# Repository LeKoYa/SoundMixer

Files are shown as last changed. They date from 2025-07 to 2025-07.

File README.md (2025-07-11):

# SoundMixer
A deej-powered Soundmixer for individual volume control with rotary encoders, leds, buttons and oled support. I've also made an enclosure that is supposed to be mounted below a table.



This is still an early version and rebuilding your own might become very tricky. I am actively working on a second version that will be easier to build and assemble.

# Hardware
The soundmixer uses the following things:
- Arduino nano
- 5x Custom PCBs with 25 ws2812 LEDs and rotary encoder
- 1x 1.3" i2c oled screen (ssd1306)
- 2x mx-switch
- 2x pull-up resistors
- A lot of cables

### LED-PCB
For the LEDs i've designed a custom pcb with a size of 3x3cm. On the front side are 25 1010 ws2812 LEDs, neatly arranged around a rotary encoder (PEC11R-4015F-S0024). The backside features some capacitors and resistors used mainly for the encoder. It also features a small 7-pin molex picoblade connector due to the limited space.





The pcb was designed in kicad. I am still working on a version2 that features two pcbs stacked on top of each other, so the encoder does not stick out too far above the leds.

### Enclosure
The entire enclosure is 3d-printed, mainly in PLA. The diffusers in front of the led rings are made out of translucent PETG.
The parts are screwed together with some M2.5 screws. 



# Software

### PC Side
On the pc side, it uses a fork of the original deej project [found here](https://github.com/michaelwschultz/deej). 

### Arduino Side
For the arduino i wrote my own firmware (see the [software](Software) folder), with the help of platformio using some arduino libraries.

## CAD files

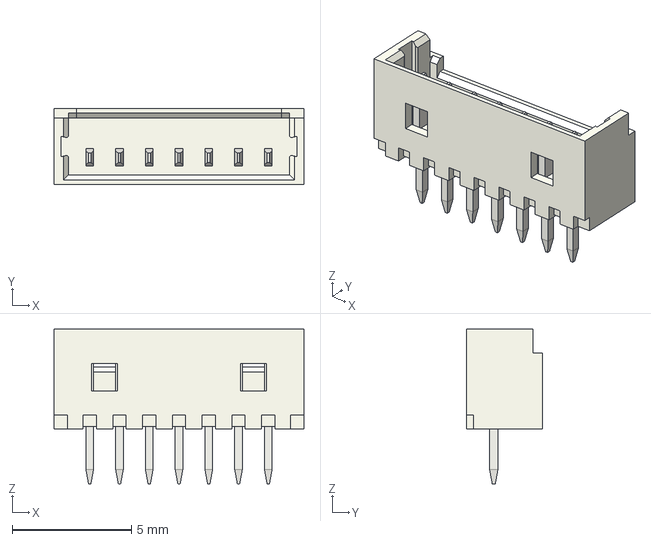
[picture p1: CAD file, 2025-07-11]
Hardware/led-pcb/3dmodels/Molex_PicoBlade_53047-0710.stp
10.5 x 3.20 x 6.50 mm

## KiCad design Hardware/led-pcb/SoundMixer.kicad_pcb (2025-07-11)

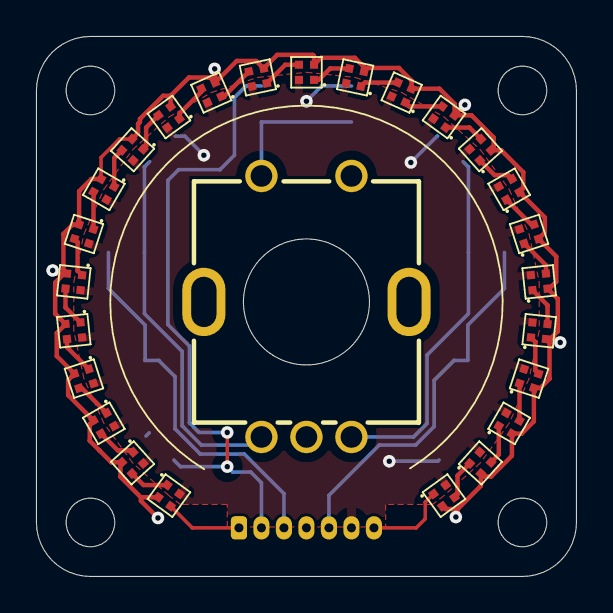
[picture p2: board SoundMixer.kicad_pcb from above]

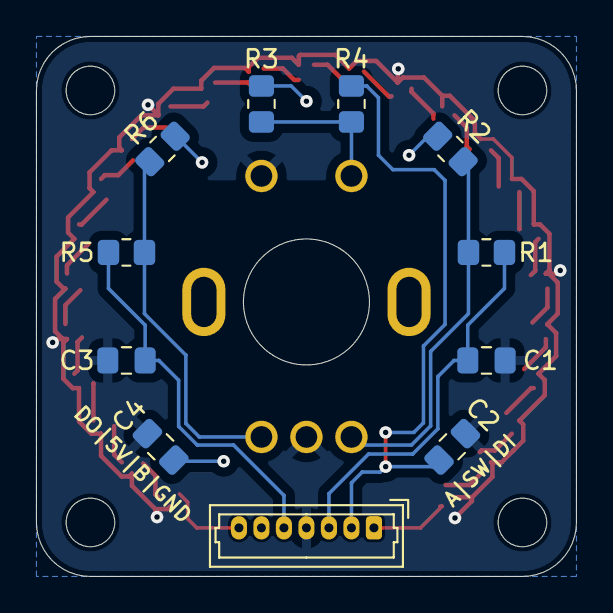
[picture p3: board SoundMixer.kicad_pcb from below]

Board: 2 copper layers, 30.0 x 30.0 mm, 41 parts (11 on the bottom side), 34 nets.

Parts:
C1, C2, C3: 0.01uF; C_0805_2012Metric_Pad1.18x1.45mm_HandSolder
C4: 4.7uF; C_0805_2012Metric_Pad1.18x1.45mm_HandSolder
H1, H2, H3, H4: MountingHole; MountingHole_2.7mm_M2.5
J1: Conn_01x07; Molex_PicoBlade_53047-0710_1x07_P1.25mm_Vertical
R1, R2, R3, R5, R6: 10K; R_0805_2012Metric_Pad1.20x1.40mm_HandSolder
R4: 1K; R_0805_2012Metric_Pad1.20x1.40mm_HandSolder
SW1: PEC11R-4015F-S0024; SW-TH_PEC11R-4XXXF-SXXXX
U1, U2, U3, U4, U5, U6, U7, U8, U9, U10, U11, U12, U13, U14, U15, U16, U17, U18, U19, U20, U21, U22, U23, U24, U25: XL-1010RGBC-WS2812B; LED-SMD_4P-L1.0-W1.0-TL_XL-1010RGBC-WS2812B

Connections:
/Encoder_A: C1.1, J1.3, R1.1
/Encoder_B: C3.1, J1.5, R5.2
/Encoder_Button: C2.1, J1.2, R4.2
DIN: J1.1, U1.4 (DIN)
DOUT: J1.7, U25.1 (DOUT)
GND: C1.2, C2.2, C3.2, C4.2, J1.4, SW1.2, SW1.C, U1.3 (GND), U2.3 (GND), U3.3 (GND), U4.3 (GND), U5.3 (GND), U6.3 (GND), U7.3 (GND), U8.3 (GND), U9.3 (GND), U10.3 (GND), U11.3 (GND), U12.3 (GND), U13.3 (GND), U14.3 (GND), U15.3 (GND), U16.3 (GND), U17.3 (GND), U18.3 (GND), U19.3 (GND), U20.3 (GND), U21.3 (GND), U22.3 (GND), U23.3 (GND), U24.3 (GND), U25.3 (GND)
unnamed: R1.2, R2.1, SW1.A
unnamed: R3.2, R4.1, SW1.1
unnamed: R5.1, R6.1, SW1.B
unnamed: U1.1 (DOUT), U2.4 (DIN)
unnamed: U2.1 (DOUT), U3.4 (DIN)
unnamed: U3.1 (DOUT), U4.4 (DIN)
unnamed: U4.1 (DOUT), U5.4 (DIN)
unnamed: U5.1 (DOUT), U6.4 (DIN)
unnamed: U6.1 (DOUT), U7.4 (DIN)
unnamed: U7.1 (DOUT), U8.4 (DIN)
unnamed: U8.1 (DOUT), U9.4 (DIN)
unnamed: U9.1 (DOUT), U10.4 (DIN)
unnamed: U10.1 (DOUT), U11.4 (DIN)
unnamed: U11.1 (DOUT), U12.4 (DIN)
unnamed: U12.1 (DOUT), U13.4 (DIN)
unnamed: U13.1 (DOUT), U14.4 (DIN)
unnamed: U14.1 (DOUT), U15.4 (DIN)
unnamed: U15.1 (DOUT), U16.4 (DIN)
unnamed: U16.1 (DOUT), U17.4 (DIN)
unnamed: U17.1 (DOUT), U18.4 (DIN)
unnamed: U18.1 (DOUT), U19.4 (DIN)
unnamed: U19.1 (DOUT), U20.4 (DIN)
unnamed: U20.1 (DOUT), U21.4 (DIN)
unnamed: U21.1 (DOUT), U22.4 (DIN)
unnamed: U22.1 (DOUT), U23.4 (DIN)
unnamed: U23.1 (DOUT), U24.4 (DIN)
unnamed: U24.1 (DOUT), U25.4 (DIN)
VCC: C4.1, J1.6, R2.2, R3.1, R6.2, U1.2 (VDD), U2.2 (VDD), U3.2 (VDD), U4.2 (VDD), U5.2 (VDD), U6.2 (VDD), U7.2 (VDD), U8.2 (VDD), U9.2 (VDD), U10.2 (VDD), U11.2 (VDD), U12.2 (VDD), U13.2 (VDD), U14.2 (VDD), U15.2 (VDD), U16.2 (VDD), U17.2 (VDD), U18.2 (VDD), U19.2 (VDD), U20.2 (VDD), U21.2 (VDD), U22.2 (VDD), U23.2 (VDD), U24.2 (VDD), U25.2 (VDD)
